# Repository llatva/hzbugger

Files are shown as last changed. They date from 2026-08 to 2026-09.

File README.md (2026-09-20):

# hzbugger

Hzbugger is an STM32F103C8T6-based Black Magic Probe compatible debugger by Lasse OH3HZB. 

Bottom side silkscreen created using AI tools (intended for *black PCB* as in pictures below). 

Basic functionality works out-of-box with BMP bluepill image. Extra LEDs and AUX header requires fw customization.
See [BlackMagic Probe adaptation guide](./blackmagic-probe-adaptation-guide.md) for firmware-porting and usage details.

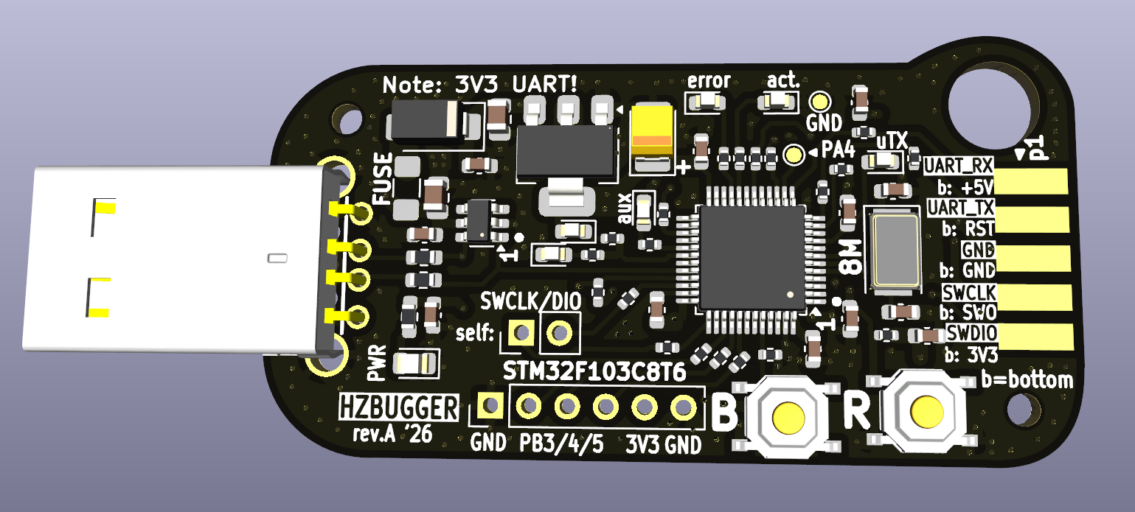
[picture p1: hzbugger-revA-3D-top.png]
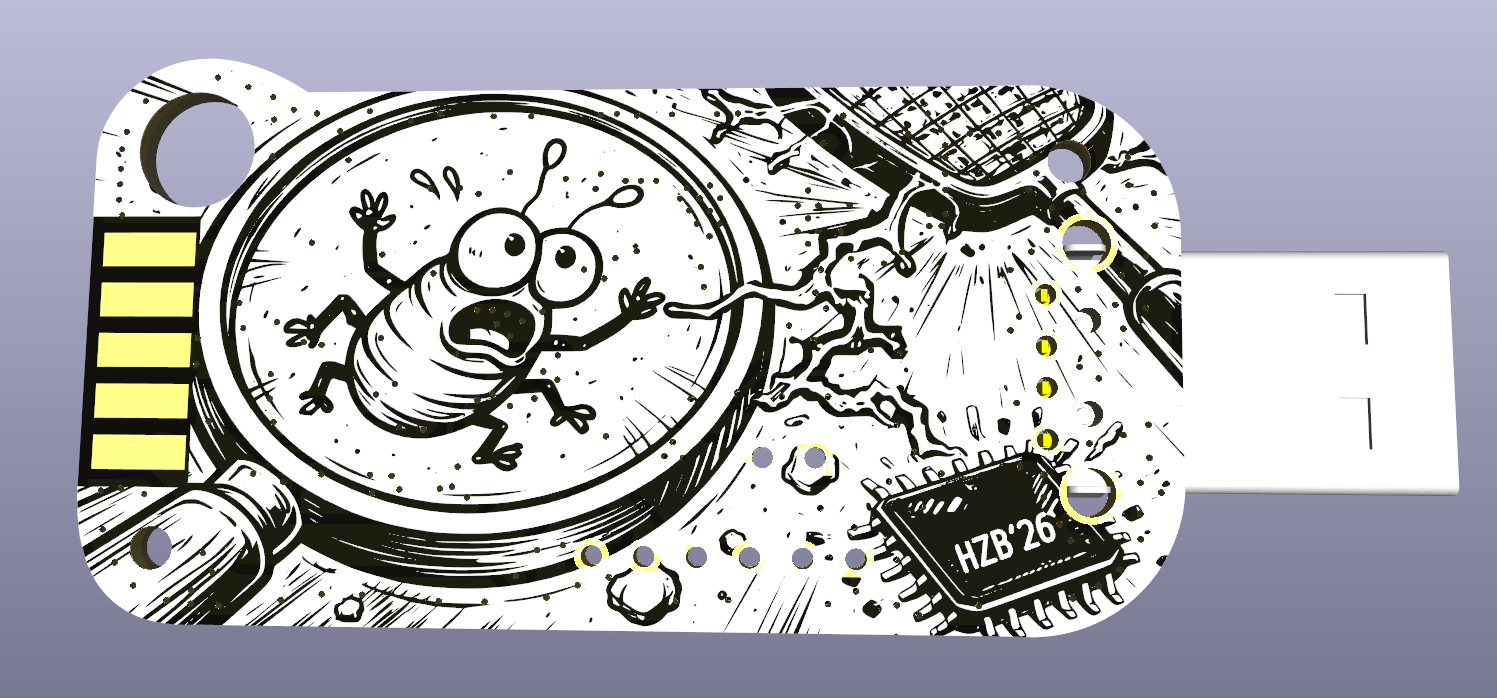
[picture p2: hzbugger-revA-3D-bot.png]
 

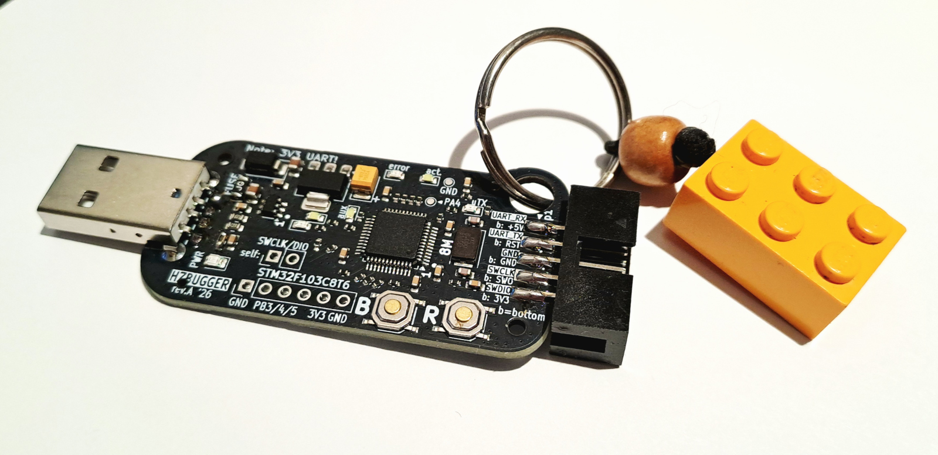
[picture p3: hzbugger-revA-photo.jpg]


## Schematic

<a href="./hzbugger-revA-schematic.pdf">hzbugger-revA-schematic.pdf</a>

## Getting started: Using Hzbugger to flash firmware

### Connect the probe

The device should enumerate as /dev/ttyACM0 and /dev/ttyACM1 (on Linux).

### Build the firmware

Build the application so that the output includes an ELF file containing debug information.
For example:

    build/my_application.elf

The ELF file is used both for programming the target and for debugging.
Start GDB from the shell:

    arm-none-eabi-gdb build/my_application.elf

### Flash the firmware

Then run the following commands inside GDB:

    target extended-remote /dev/ttyACM1
    monitor erase_mass
    load
    monitor reset

## Getting started: Using Hzbugger as debugger with Visual Studio Code (vscode)

### Required software

- Visual Studio Code
- ARM GNU Toolchain
- `arm-none-eabi-gdb`
- The Cortex-Debug VS Code extension

The firmware should be built with debug information enabled, for example:

    -g

For development builds, it is also useful to disable compiler optimization:

    -O0

This makes source-level debugging easier.

### Create the VS Code configuration

Create the following file in your project:

    .vscode/launch.json

Add debug configuration:

    {
        "version": "0.2.0",
        "configurations": [
            {
                "name": "Debug with Black Magic Probe",
                "type": "cortex-debug",
                "request": "launch",
                "servertype": "bmp",
                "executable": "${workspaceFolder}/build/my_application.elf",
                "device": "YOUR_MCU",
                "cwd": "${workspaceFolder}",
                "runToEntryPoint": "main"
            }
        ]
    }

Replace `YOUR_MCU` with the name of your target MCU.

Also update the `executable` path if your ELF file is located somewhere else.

### Start debugging

Connect Hzbugger and start the debugger in VS Code using `F5` button.
VS Code will use GDB to connect to the Hzbugger and start a debug session.
You can then use the normal VS Code debugging features:

- Set breakpoints
- Step over — `F10`
- Step into — `F11`
- Step out — `Shift+F11`
- Continue — `F5`
- Inspect variables
- Inspect the call stack
- Use the Watch window
- Inspect registers and memory

---

### Useful Commands

* Check the ARM GDB installation: `arm-none-eabi-gdb --version`
* Find the Hzbugger device: `ls /dev/ttyACM`
* Start GDB manually: `arm-none-eabi-gdb build/my_application.elf`
* Connect to the probe: `target extended-remote /dev/ttyACM1`
* Erase flash: `monitor erase_mass`
* Flash the firmware: `load`
* Reset the target: `monitor reset`

(Hzbugger acts as a GDB server itself so you do not need to start a separate (e.g. OpenOCD) GDB server)

## References

* Website of the Black Magic Probe: https://black-magic.org/
* BMP firmware repository: https://codeberg.org/blackmagic-debug/blackmagic

## LICENSE

CERN-OHL-S (strongly reciprocal), see [LICENSE.txt](./LICENSE.txt) for details.

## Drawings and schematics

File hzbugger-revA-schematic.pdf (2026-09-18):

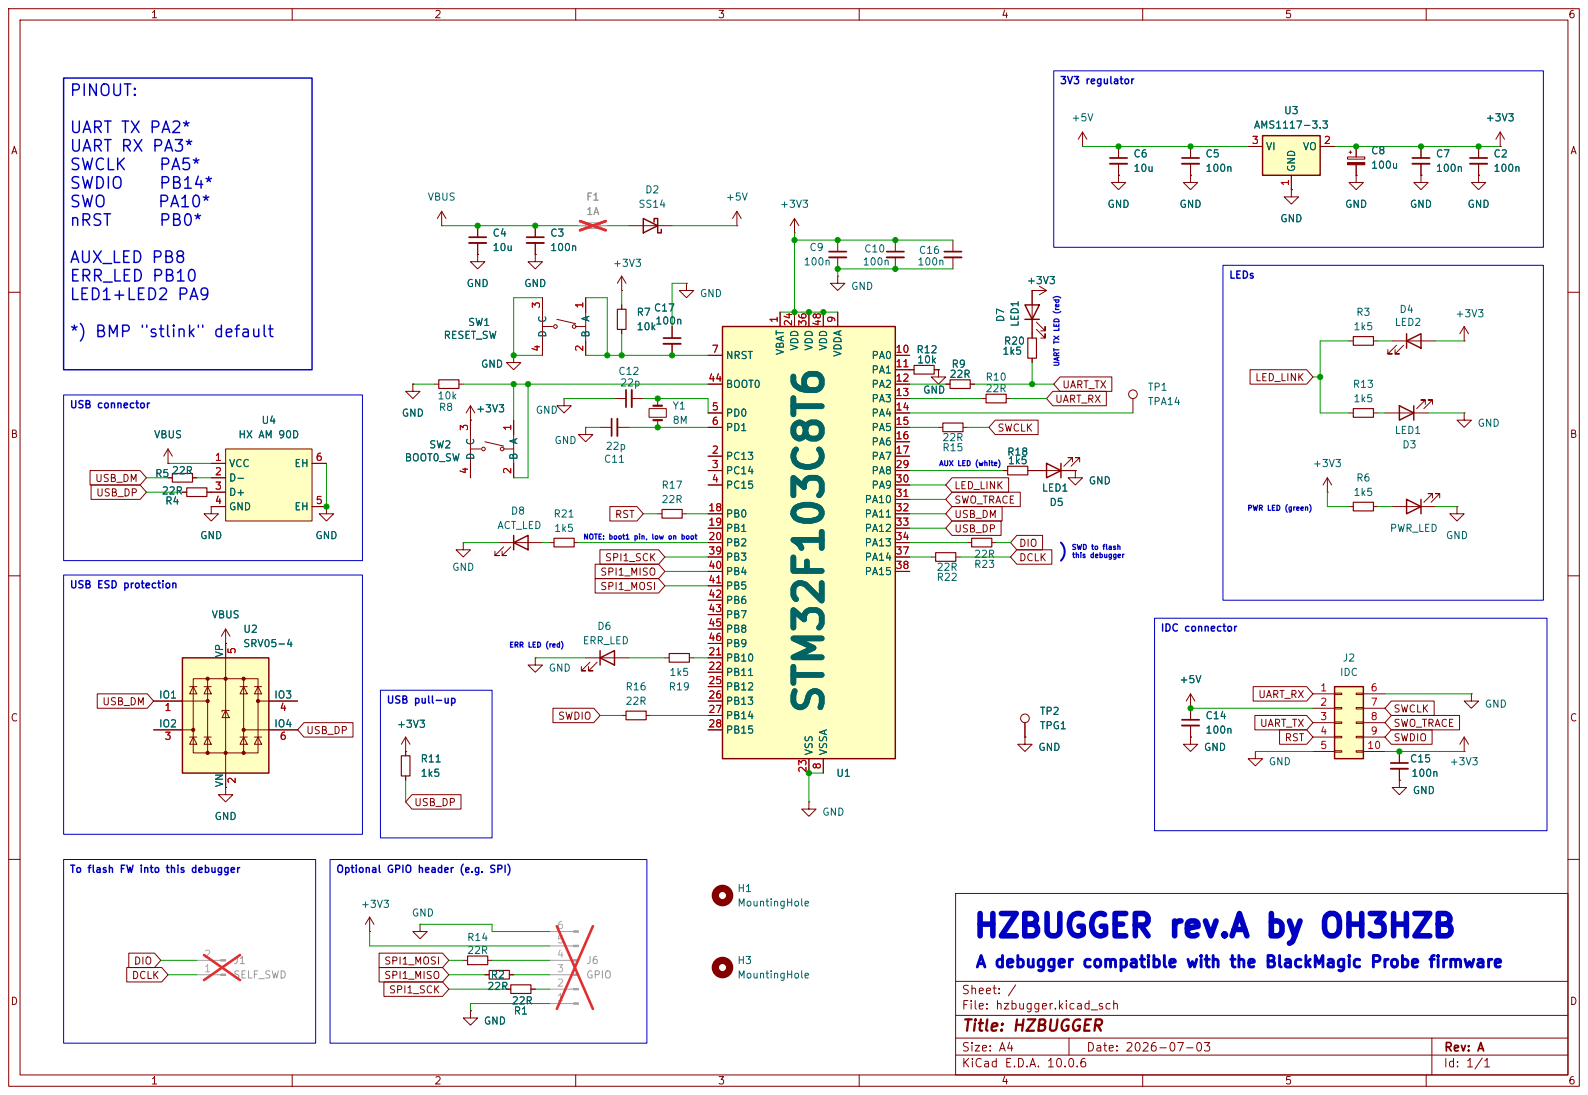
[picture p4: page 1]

3V3 regulator USB connector USB ESD protection
PINOUT:

A debugger compatible with the BlackMagic Probe firmware UART TX LED (red)
22RD7 LED1 R20

this debugger HZBUGGER rev.A by OH3HZB

IDC connector USB pull-up

Size: A4 | Rev: A
KiCad E.D.A. 10.0.6 | Id: 1/1

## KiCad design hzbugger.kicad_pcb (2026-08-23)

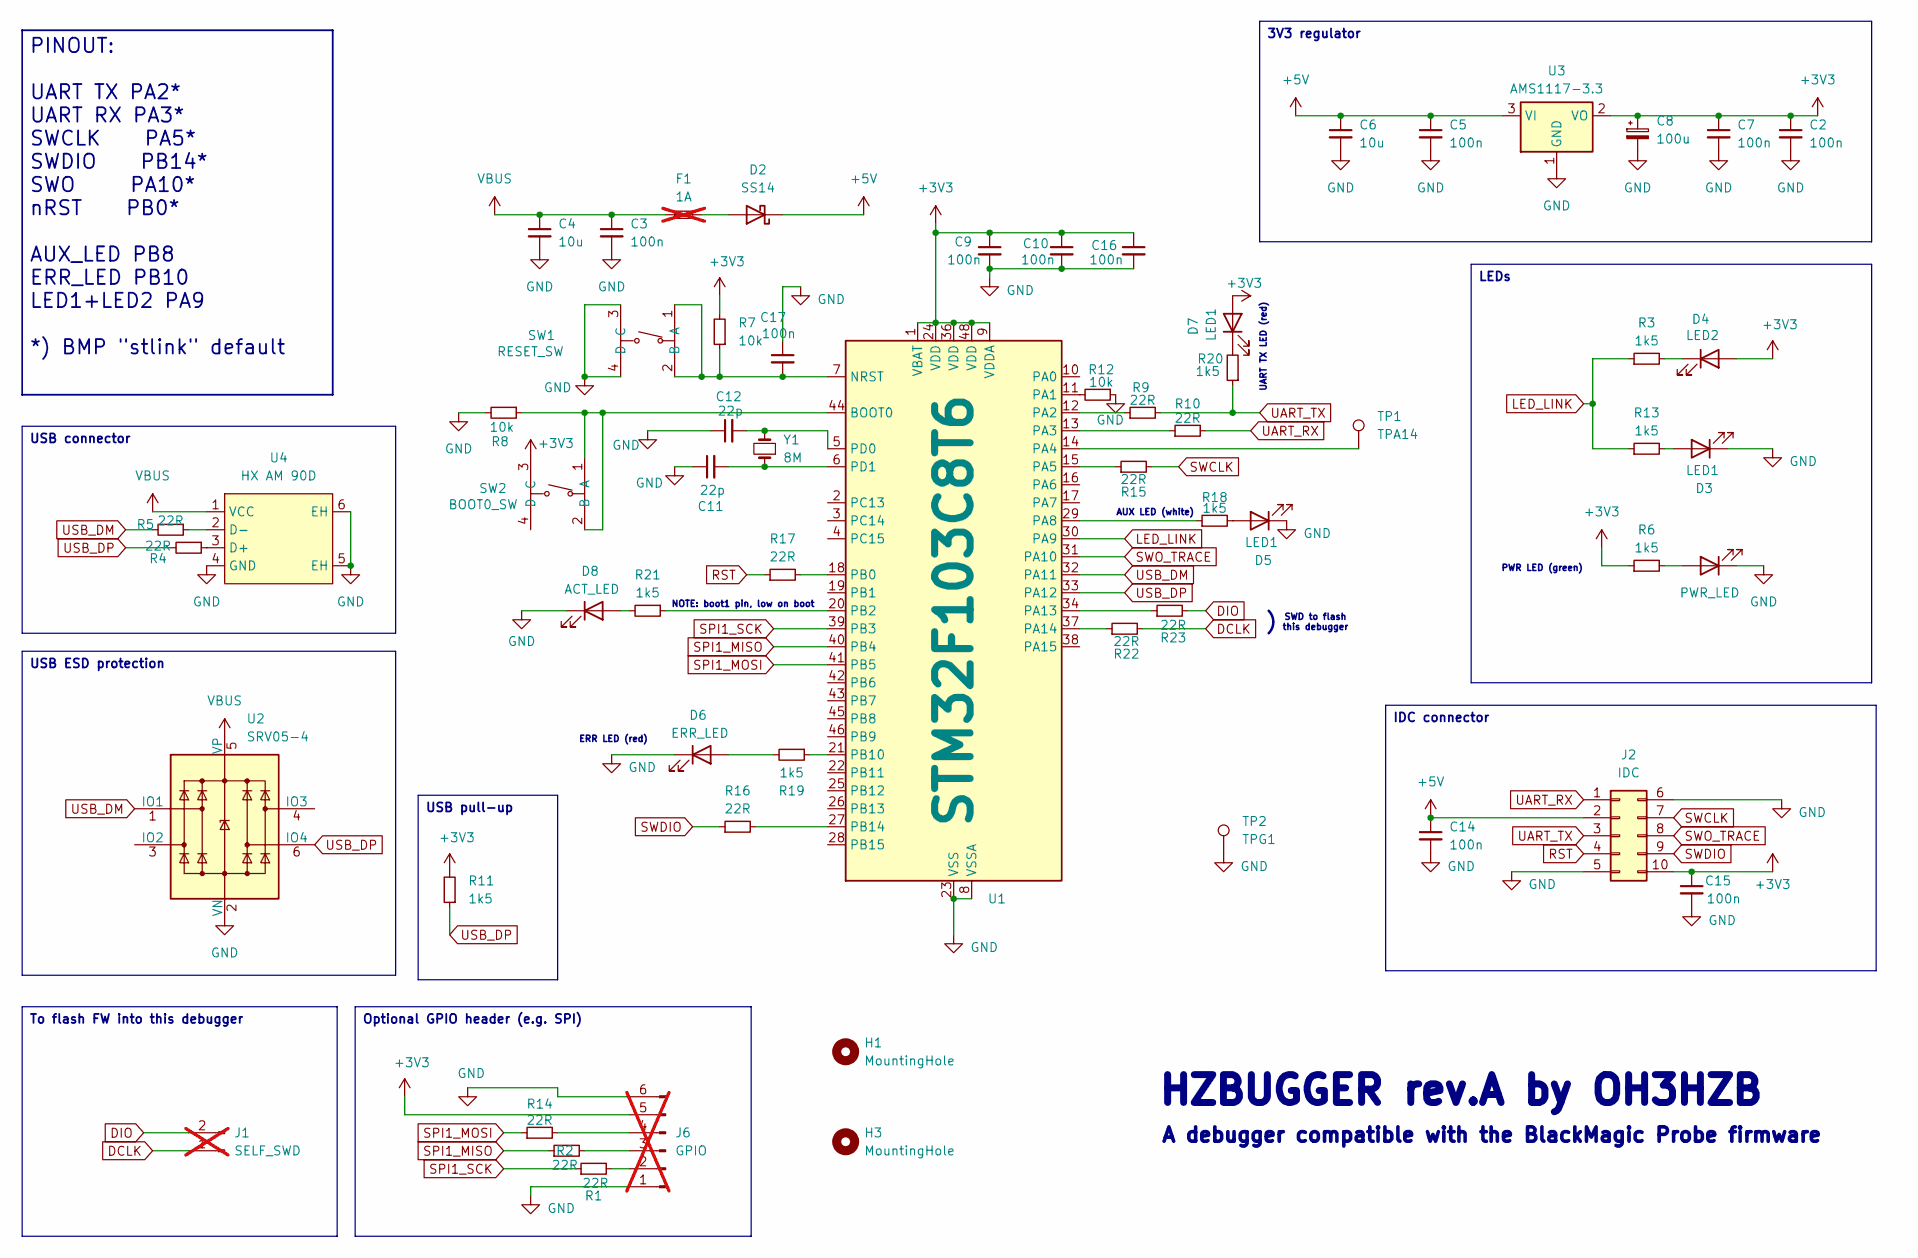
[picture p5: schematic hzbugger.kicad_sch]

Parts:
C2, C3, C5, C7, C9, C10, C14, C15, C16, C17: 100n; C_0603_1608Metric; LCSC C14663
C4, C6: 10u; C_0805_2012Metric; LCSC C15850
C8: 100u; CP_EIA-3528-21_Kemet-B_Pad1.50x2.35mm_HandSolder; LCSC C16133
C11, C12: 22p; C_0603_1608Metric; LCSC C1653
D1: PWR_LED; LED_0805_2012Metric; LCSC C2297
D2: SS14; D_SMA; LCSC C2480
D3, D7: LED1; LED_0603_1608Metric; LCSC C2286
D4: LED2; LED_0603_1608Metric; LCSC C2290
D5: LED1; LED_0603_1608Metric; LCSC C2290
D6: ERR_LED; LED_0603_1608Metric; LCSC C2286
D8: ACT_LED; LED_0603_1608Metric; LCSC C2290
F1: 1A; Fuse_1206_3216Metric_Pad1.42x1.75mm_HandSolder; LCSC DNP; not fitted
H1, H3: MountingHole; MountingHole_2.1mm
J1: SELF_SWD; PinHeader_1x02_P2.54mm_Vertical; LCSC DNP; not fitted
J2: IDC; SMD-pcbend-IDC-Header_2x05_P2.54mm; LCSC DNP
J6: GPIO; PinHeader_1x06_P2.54mm_Vertical; LCSC DNP; not fitted
R1, R2, R9, R10, R14, R15, R16, R17, R22, R23: 22R; R_0402_1005Metric; LCSC C25092
R3, R13, R18, R19, R20, R21: 1k5; R_0402_1005Metric; LCSC C25867
R4, R5: 22R; R_0603_1608Metric; LCSC C23345
R6: 1k5; R_0603_1608Metric_Pad0.98x0.95mm_HandSolder; LCSC C22843
R7, R8, R12: 10k; R_0402_1005Metric; LCSC C25744
R11: 1k5; R_0402_1005Metric_Pad0.72x0.64mm_HandSolder; LCSC C25867
SW1: RESET_SW; SW-SMD_4P-L5.1-W5.1-P3.70-LS6.5-TL_H1.5; LCSC C318884
SW2: BOOT0_SW; SW-SMD_4P-L5.1-W5.1-P3.70-LS6.5-TL_H1.5; LCSC C318884
TP1: TPA14; TestPoint_Pad_D1.0mm; LCSC DNP
TP2: TPG1; TestPoint_Pad_D1.0mm; LCSC DNP
U1: STM32F103C8T6; LQFP-48_7x7mm_P0.5mm; LCSC C8734
U2: SRV05-4; SOT-23-6; LCSC C7420376
U3: AMS1117-3.3; SOT-223-3_TabPin2; LCSC C6186
U4: HX AM 90D; USB-A-TH_HANXIA_HXAM90D; LCSC C5160314
Y1: 8M; Crystal_SMD_5032-2Pin_5.0x3.2mm; LCSC C115962

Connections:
+3V3: C2.1, C7.1, C8.1, C9.1, C10.1, C15.1, C16.1, D4.2 (A), D7.2 (A), J2.10, J6.5, R6.1, R7.2, R11.2, SW2.3 (C), U1.1 (VBAT), U1.9 (VDDA), U1.24 (VDD), U1.36 (VDD), U1.48 (VDD), U3.2 (VO)
+5V: C5.1, C6.1, C14.1, D2.1 (K), J2.2, U3.3 (VI)
DCLK: J1.1, R22.2
DIO: J1.2, R23.2
GND: C2.2, C3.2, C4.2, C5.2, C6.2, C7.2, C8.2, C9.2, C10.2, C11.1, C12.1, C14.2, C15.2, C16.2, C17.1, D1.1 (K), D3.1 (K), D5.1 (K), D6.1 (K), D8.1 (K), J2.5, J2.6, J6.1, J6.6, R8.2, R12.1, SW1.3 (C), SW1.4 (D), TP2.1 (1_1), U1.8 (VSSA), U1.23 (VSS), U1.35 (VSS), U1.47 (VSS), U2.2 (VN), U3.1 (GND), U4.4 (GND), U4.5 (EH), U4.6 (EH)
LED_LINK: R3.1, R13.1, U1.30 (PA9)
unnamed: D1.2 (A), R6.2
unnamed: D2.2 (A), F1.1
unnamed: D3.2 (A), R13.2
unnamed: D4.1 (K), R3.2
unnamed: D5.2 (A), R18.2
unnamed: D6.2 (A), R19.2
unnamed: D7.1 (K), R20.2
unnamed: D8.2 (A), R21.2
unnamed: J6.2, R1.2
unnamed: J6.3, R2.2
unnamed: J6.4, R14.2
unnamed: C17.2, R7.1, SW1.1 (A), SW1.2 (B), U1.7 (NRST)
unnamed: R8.1, SW2.1 (A), SW2.2 (B), U1.44 (BOOT0)
unnamed: R12.2, U1.11 (PA1)
unnamed: R9.1, U1.12 (PA2)
unnamed: R10.1, U1.13 (PA3)
unnamed: TP1.1 (1_1), U1.14 (PA4)
unnamed: R15.1, U1.15 (PA5)
unnamed: R18.1, U1.29 (PA8)
unnamed: R23.1, U1.34 (PA13)
unnamed: R22.1, U1.37 (PA14)
unnamed: R17.2, U1.18 (PB0)
unnamed: R21.1, U1.20 (PB2)
unnamed: R19.1, U1.21 (PB10)
unnamed: R16.2, U1.27 (PB14)
unnamed: C12.2, U1.5 (PD0), Y1.2
unnamed: C11.2, U1.6 (PD1), Y1.1
unnamed: R4.1, U4.3 (D+)
unnamed: R5.1, U4.2 (D-)
RST: J2.4, R17.1
SPI1_MISO: R2.1, U1.40 (PB4)
SPI1_MOSI: R14.1, U1.41 (PB5)
SPI1_SCK: R1.1, U1.39 (PB3)
SWCLK: J2.7, R15.2
SWDIO: J2.9, R16.1
SWO_TRACE: J2.8, U1.31 (PA10)
UART_RX: J2.1, R10.2
UART_TX: J2.3, R9.2, R20.1
USB_DM: R5.2, U1.32 (PA11), U2.1 (IO1)
USB_DP: R4.2, R11.1, U1.33 (PA12), U2.6 (IO4)
VBUS: C3.1, C4.1, F1.2, U2.5 (VP), U4.1 (VCC)

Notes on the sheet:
A debugger compatible with the BlackMagic Probe firmware
HZBUGGER rev.A by OH3HZB
ERR LED (red)
SWD to flash this debugger
NOTE: boot1 pin, low on boot
UART TX LED (red)
PWR LED (green)
AUX LED (white)
Optional GPIO header (e.g. SPI)
3V3 regulator
To flash FW into this debugger
USB connector
LEDs
USB pull-up
PINOUT: UART TX PA2* UART RX PA3* SWCLK PA5* SWDIO PB14* SWO PA10* nRST PB0* AUX_LED PB8 ERR_LED PB10 LED1+LED2 PA9 *) BMP "stlink" default
IDC connector
USB ESD protection

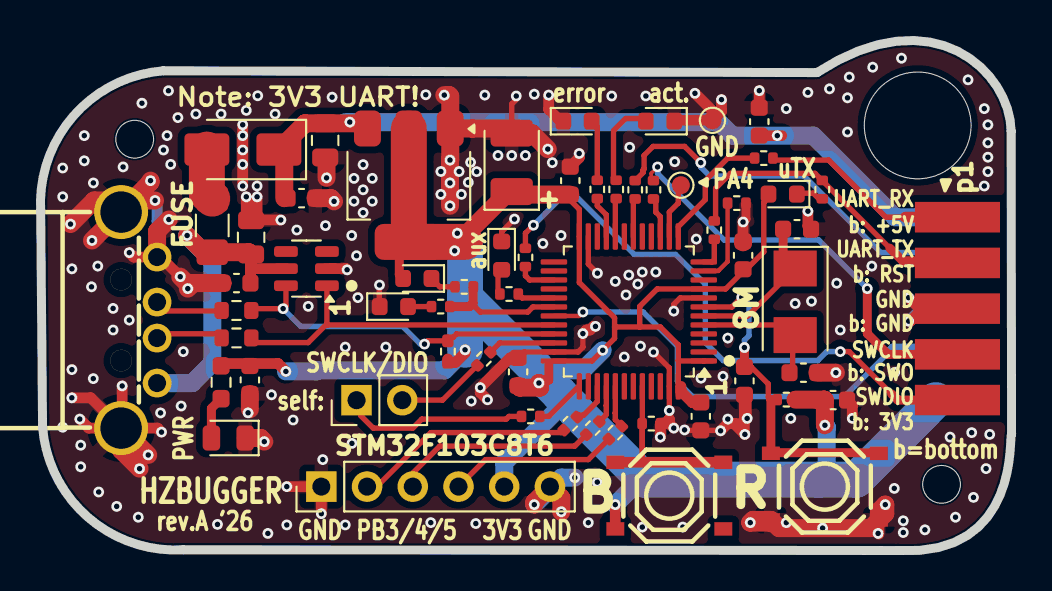
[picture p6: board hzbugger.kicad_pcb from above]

Board: 2 copper layers, 53.9 x 28.3 mm, 61 parts (0 on the bottom side), 47 nets.

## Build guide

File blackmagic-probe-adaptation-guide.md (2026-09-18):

# Black Magic Probe Firmware Adaptation Guide for Hzbugger

## Overview

Hzbugger is a Black Magic Probe (BMP)-compatible SWD debugger. This guide walks through adapting upstream BMP firmware to the Hzbugger hardware, highlights the key firmware features, and provides concrete examples for using both GDB debugging and the built-in UART passthrough. The goal is to help you build a firmware image that exposes:

- **Simultaneous SWD + UART** using two USB CDC ACM serial ports.
- **GDB server integration** over the primary USB serial port.
- **Generic serial console access** over the secondary USB serial port.
- **Target connection over IDC 2x5** with SWD, UART, reset, and power rails.

> Note: This guide assumes you are familiar with the upstream Black Magic Probe firmware structure. When in doubt, refer to the upstream BMP documentation for the canonical build steps.

## Prerequisites

- The upstream Black Magic Probe firmware source.
- A toolchain such as `arm-none-eabi-gcc`.
- USB access to the Hzbugger device for flashing.
- The Hzbugger schematic or silk labels for pin and power-rail reference.

## 1) Identify the Hzbugger Hardware Mapping

Before changing firmware, map the Hzbugger pins and peripherals to BMP firmware expectations.

### Main target connector: J2 (IDC 2x5, 2.54 mm)

Use this as the canonical target pinout:

| Pin | Signal |
|---|---|
| 1 | UART_TX |
| 2 | UART_RX |
| 3 | SWO_TRACE |
| 4 | RST |
| 5 | GND |
| 6 | SWDIO |
| 7 | SWCLK |
| 8 | +3V3 |
| 9 | +5V |
| 10 | GND |

### Onboard programming connector: J4 (1x4, labeled SWD)

This header is for programming/debugging the Hzbugger MCU itself:

| Pin | Signal | MCU pin |
|---|---|---|
| 1 | GND | GND |
| 2 | +3V3 | +3V3 |
| 3 | DCLK | PA14 |
| 4 | DIO | PA13 |

### Auxiliary GPIO connector: J6 (1x6)

| Pin | Signal |
|---|---|
| 1 | GND |
| 2 | PB3 / SPI1_SCK (via 22R) |
| 3 | PB4 / SPI1_MISO (via 22R) |
| 4 | PB5 / SPI1_MOSI (via 22R) |
| 5 | +3V3 |
| 6 | GND |

### Power behavior on rev.A

- USB VBUS provides the board +5V rail.
- AMS1117-3.3 generates +3V3.
- J2 exposes both +3V3 (pin 8) and +5V (pin 9) simultaneously.
- There is no onboard selector that switches target output between 3.3V and 5V.

## 2) Create a New BMP Platform Definition

In the BMP firmware tree, create a new platform target (or copy the closest existing one) so the build system produces firmware tailored to Hzbugger.

Typical steps include:

1. **Add a platform directory** (e.g., `platforms/hzbugger/`).
2. **Define GPIO pin mappings** for SWDIO, SWCLK, UART TX/RX, LEDs, and reset.
3. **Set USB descriptors** (product name like `Hzbugger` is useful for users).
4. **Enable dual CDC ACM ports** to expose both GDB and UART.

Keep the changes minimal: only update what is necessary for the Hzbugger pinout and USB identification.

## 3) Build and Flash the Firmware

Once the platform definition is in place, build the firmware using the normal BMP workflow. A typical sequence looks like this:

```bash
make clean
make PROBE_HOST=hzbugger
```

Flash the resulting binary to the Hzbugger using your preferred method (DFU, SWD, or a board-specific bootloader).

## 4) STM32F103 DFU Bootloader Notes

Hzbugger uses an **STM32F103** MCU, which has a built-in ROM DFU bootloader. However, on this board revision, BOOT0 is not routed to a dedicated external jumper/switch.

### Entering DFU Mode on this board

ROM DFU still requires **BOOT0 = 1** and reset, but rev.A does not provide a dedicated BOOT0 user control. In practice:

- The default build is intended to be flashed/debugged over SWD (J4/J2).
- DFU on this hardware requires board-level rework or temporary BOOT0 injection.
- BOOT1 (PB2) remains tied low by default, which is the normal configuration.

### If DFU is available in your setup

When BOOT0 is externally forced high and the device enumerates in DFU mode, flash as usual (Linux example):

```bash
dfu-util -l
dfu-util -a 0 -s 0x08000000:leave -D blackmagic.bin
```

On Windows/macOS, use **STM32CubeProgrammer** to program at `0x08000000`.

After flashing, restore normal boot configuration and reset.

## 5) Verify USB Enumeration

When the firmware is running, the Hzbugger should enumerate as **two serial devices**:

- **Primary CDC port:** BMP GDB server.
- **Secondary CDC port:** UART passthrough.

On Linux, you might see:

- `/dev/ttyACM0` (GDB)
- `/dev/ttyACM1` (UART)

> The exact numbering may vary depending on the system. Identify by unplugging/replugging or checking `dmesg` output.

## 6) Using GDB Over SWD (Primary Serial Port)

Connect GDB to the probe using the primary port. Example workflow:

```bash
arm-none-eabi-gdb build/firmware.elf
```

In the GDB session:

```gdb
target extended-remote /dev/ttyACM0
monitor swdp_scan
attach 1
load
continue
```

### Common GDB Commands

- `monitor swdp_scan` — list available SWD targets.
- `attach <n>` — attach to target number `n`.
- `load` — program the target.
- `reset` — reset the target after loading.

This gives a full-featured debugging experience (breakpoints, memory inspection, etc.).

## 7) Using UART Passthrough (Secondary Serial Port)

The second CDC port is a transparent serial bridge to the target MCU UART pins. Use it as a normal serial terminal:

```bash
screen /dev/ttyACM1 115200
```

Or with `picocom`:

```bash
picocom -b 115200 /dev/ttyACM1
```

This port can be used for logging, CLI shells, or any debug printf output from the target.

## 8) Simultaneous SWD + UART Usage

Hzbugger supports **simultaneous SWD debugging and UART logging**. Typical flow:

1. Connect GDB to the primary port (`/dev/ttyACM0`).
2. Start a serial terminal on the secondary port (`/dev/ttyACM1`).
3. Debug while streaming logs in real time.

This is especially useful for correlating firmware logs with breakpoints or crash reproduction.

## 9) Target Power Output (+3V3 / +5V rails on J2)

Hzbugger exposes **both +3V3 and +5V rails** on J2:

- **J2 pin 8:** +3V3
- **J2 pin 9:** +5V

There is no onboard selector that switches one rail to the other. Choose the correct rail in your cable/target-side wiring and avoid back-powering conflicts.

> Always verify target voltage requirements before connecting either power rail.

## 10) Quick Troubleshooting Checklist

- **No USB ports appear:** verify firmware is flashed and USB cable is data-capable.
- **GDB fails to connect:** check SWD wiring and common ground, then run `monitor swdp_scan`.
- **UART has no output:** verify target baud rate and RX/TX pin orientation.
- **DFU mode not detected:** confirm BOOT0 is high, BOOT1 is low, and reset was applied.
- **Unstable target behavior:** verify you are using the intended rail (+3V3 or +5V) and avoid double power sources.

## Summary

By defining a minimal BMP platform for Hzbugger, you can unlock full SWD debugging alongside real-time UART logging. With dual CDC ACM ports and explicit +3V3/+5V target rail pins, Hzbugger becomes a compact, flexible debugging tool for modern ARM microcontrollers.

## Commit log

2026-01-01 to GH
    [hzbugger.kicad_pcb, hzbugger.kicad_sch]
2026-01-01 to be continued
    [hzbugger.kicad_pcb]
2026-01-03 silks etc
    [hzbugger.kicad_pcb, hzbugger.kicad_sch]
2026-01-04 right USB connector, etc
    [hzbugger.kicad_pcb, hzbugger.kicad_sch]
2026-01-04 LCSC codes
    [hzbugger.kicad_pcb, hzbugger.kicad_sch]
2026-01-04 show R6 3D
    [hzbugger.kicad_pcb, hzbugger.kicad_sch]
2026-01-04 other model, reset sw now in place
    [hzbugger.kicad_pcb, hzbugger.kicad_sch]
2026-01-04 jlc settings for gerbers
    [hzbugger.kicad_pcb]
2026-01-04 edit header footprint to remove silk lines
    [hzbugger.kicad_pcb]
2026-01-06 change xtal package etc
    [hzbugger.kicad_pcb, hzbugger.kicad_sch]
2026-01-06 sw lcsc etc
    [hzbugger.kicad_pcb, hzbugger.kicad_sch]
2026-01-07 remove pinhead, just idc left
    [hzbugger.kicad_pcb, hzbugger.kicad_sch]
2026-01-24 layout further
    [hzbugger.kicad_pcb, hzbugger.kicad_sch]
2026-01-30 gfx etc
    [hzbugger.kicad_pcb]
2026-01-31 Add Black Magic Probe adaptation guide
2026-01-31 Add STM32F103 DFU bootloader guidance
2026-02-01 hide c8 label ä
    [hzbugger.kicad_pcb]
2026-02-06 usr led
    [hzbugger.kicad_pcb, hzbugger.kicad_sch]
2026-02-06 some fine-tuning
    [hzbugger.kicad_pcb]
2026-02-07 layout enhancements
    [hzbugger.kicad_pcb]
2026-02-07 IDC pad lengths
    [hzbugger.kicad_pcb, hzbugger.kicad_sch]
2026-02-07 some final adjustments
    [hzbugger.kicad_pcb, hzbugger.kicad_sch]
2026-02-07 outline, to fit idc
    [hzbugger.kicad_pcb]
2026-02-19 tx led
    [hzbugger.kicad_pcb, hzbugger.kicad_sch]
2026-02-27 final adjustments
    [hzbugger.kicad_pcb]
2026-02-27 one via in wrong place
    [hzbugger.kicad_pcb]
2026-03-13 hole for keychain
    [hzbugger.kicad_pcb]
2026-04-30 Document verified rev.A connector pinouts and power behavior
    Agent-Logs-Url: https://github.com/llatva/hzbugger/sessions/458d2470-58cf-4c34-8422-1347c02f1809
2026-05-23 some enhancements, corrected LCSC code for 0422 1k5 R
    [hzbugger.kicad_pcb, hzbugger.kicad_sch]
2026-07-03 pinout enhancements, layout, physical outline + gitignore updateg
    [hzbugger.kicad_pcb, hzbugger.kicad_sch]
2026-07-03 form factor, mounting holes
    [hzbugger.kicad_pcb, hzbugger.kicad_sch]
2026-07-03 some finalisation, schema style etc
    [hzbugger.kicad_pcb, hzbugger.kicad_sch]
2026-07-03 further some fine-tuning
    [hzbugger.kicad_pcb, hzbugger.kicad_sch]
2026-07-03 DRC seems to be ok
    [hzbugger.kicad_pcb]
2026-07-03 gnd via placement still
    [hzbugger.kicad_pcb]
2026-07-03 minor silk adjustment
    [hzbugger.kicad_pcb]
2026-07-04 minor adjustments into outline
    [hzbugger.kicad_pcb, hzbugger.kicad_sch]
2026-08-23 silks, fix DRC error
    [hzbugger.kicad_pcb]
2026-09-18 Update README with PCB layout and design credits
    Added credit for PCB layout and silkscreen design.
2026-09-18 schema pdf
    [hzbugger.kicad_sch]
2026-09-18 Add schematic section to README
    Added schematic link to README.
2026-09-18 Fix link to hzbugger-revA-schematic.pdf
2026-09-19 Fix typo in README for Black Magic Probe
